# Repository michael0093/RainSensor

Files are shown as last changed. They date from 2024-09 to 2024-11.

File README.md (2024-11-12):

# RainSensor
Anti-Corrosion Rain Sensor

## Overview
Unlike the cheap rain sensors that corrode quickly this design uses a small AC signal to detect rain either resistively or capacitively. The AC signal is small enough to be below the voltage required for electrochemical corrosion thereby extending the sensor life considerably. 

In addition, this design features both analog and digital outputs and can operate from 3.3V or 5V. The on-board heater can also operate automatically when moisture is detected, or manually via a control pin.

## Pin Description
| Nbr | Name | Description 			| Specifications														|
| --- | ---	| --- | --- |
|  1  | HTR+ 	| Heater supply voltage | 5V input = 2W heater, 3.3V = 0.9W. 5V max								|
|  2  | GND  	| Ground 0V  			| Common 0V but intended mainly for heater current						|
|  3  | Heat  	| Heater control input	| 0V/open=off 3.3V-5V=on. In auto-heat mode can be used to read DigOut	|
|  4  | VDD  	| Logic supply voltage	| 3.3V-5V input. Typical current consumption 5-8mA					|
|  5  | GND  	| Ground 0V  			| Common 0V but intended mainly for logic voltage						|
|  6  | DigOut  | Digital output  		| 0V=no rain, VDD=rain. Recommend <5mA draw. Adjustable threshold.		|
|  7  | AnaOut	| Analog output			| 0V=no rain, VDD=rain. Recommend <5mA draw. Adjustable gain.			|

## Setup and Configuration Options
1. First decide if the Auto-Heat option is desired - refer to the last section of "Circuit Description" below. To enable auto heat, bridge jumper JP1, otherwise leave it open (default) to disable auto heat. 
2. Next, power up the board with the desired VDD (3.3V to 5V).

For resistive sensing mode follow the numbered steps below. Capacitive sensing mode is more durable but less sensitive - if this is desired then first cover the entire sensing area in a thin plastic tape (such as clear packaging tape) then follow the same steps below. The thinner the tape the better the sensitivity.

3. For analog output, cover the sensor element with some al-foil or other conductive material. In capacitive mode, make sure it is pressed against the sensor but do not touch it with your hands whilst adjusting the trimpots as that will affect the measurement.
4. Adjust the gain trimpot all the way counter clockwise (min gain) then slowly clockwise until the AnaOut voltage reaches the maximum ADC input voltage for your system. For example most ESP32 boards have a 1V ADC input maximum. The sensor is now ready for use.
5. For digital output use, remove the conductive material and instead apply a few drops of water. Adjust the DigOut Thresh trimpot until the orange LED lights to indicate moisture is detected. Then reduce the threshold very slightly (counter-clockwise) to give a little margin on the threshold point.
6. Install your sensor in a waterproof case and position it in an open area, angled to allow rain to slide off it preferably with the points of the sensor element pointing downwards.

## Circuit Description
Opamp U1A is configured as a relaxation oscillator with a frequency of about 6-8kHz. R5 and D1 on the output clamp the voltage to about 0.5Vpp independent of the supply voltage. This passes through C3 to make it AC-coupled into the rain sensor element. R6 and R7 keep the sensor biased around 0V. Opamp U1B is a precision rectifier configuration with gain set by RV2, and its frequency response is shaped to reject 50Hz and provide peak gain at the ~8kHz oscillator frequency. The opamp charges C5 which holds the peak voltage which is then buffered by U1C for the analog output. The digital output is handled by opamp U1D in comparator configuration with hysteresis set by R11/R10 and threshold set by RV1. 

The analog and digital outputs have 100R protection resistors near the connector which limits the practical output current to 5-10mA, however changing this resistor for 0R should provide more (limited by the opamp capabilities). 
The opamp selection is not that critical: anything capable of 3.3-5V operation, with rail-to-rail output, input bias current measured in nA, and GBWP > 500k should do. None of the other parts have any special requirements except perhaps to say that any replacement for Q1 should have similarly low gate votlage and RDson, rated at at least 1A continuous.

The LEDs are a considerable current consumer in the design and could be removed to get the current consumption down to about 4mA. If using high efficiency LEDs and a dim brightness is desired, R9=100k and R12=10k works well.

You may notice that the analog output varies by around 0.1V when the digital output changes between on and off. The reason is that oscillator U1A is slightly infleucned by U1D operating as a comparator both due to U1D's current output and the fact that it is an opamp and not ideally suited for this role. To eliminate the effect, set the DigOut thresh all the way to maximum so the LED is off and always stays off. To minimise the effect whilst still keeping the digital output, reduce R12 to a larger value such as 10k, or remove it completely if you don't need the LED.

The heater is a string of 100R 1206 resistors controlled by an N MOSFET. With the "Auto Heat" jumper open (disabled) the Heat pin controls the heater state directly. When the "Auto Heat" jumper is bridged (enabled) this connects the MOSFET to the digital output signal so that when moisture is detected the heater turns on automatically. In this configuration the Heat pin actually has several functions:
 - For pure auto-heat operation, leave the Heat pin open or connected to an input pin.
 - The Heat pin will copy the state of the DigOut pin, meaning the Heat pin can be read instead of having to run another wire for DigOut and Heat pins.
 - Driving the Heat pin high or low at any time will enable or disable the heater function, thereby over-riding the automatic behaviour.

## Modifications required for Rev A
The latest schematic includes component value changes from testing, as well as a modification that require some PCB track cutting, these changes are highlighted red on the schematic and included below as changes for the next revision.
- 

## Future changes for Rev B
The modifications required for Rev A above, plus these less-important changes to improve circuit performance/robustness:
- Polarity protection at input
- Optional position for resistor divider at digital output (to allow 3.3V logic with 5V power source): better than adjusting gain trimpot
- Low-pass filter at U1B input: 
- Look to commonise the two trimpot values to 500k
- Consider a better solution for the gain trimpot since it is either 100k-150k for resistive sense mode or 500k for capacitive sense mode
- Consider if sensor element can have more capacitive coupling (closer spacing?)

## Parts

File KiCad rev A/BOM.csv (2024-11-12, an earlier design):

Reference | Value | Footprint | Qty | DNP
C1 C2 C3 C4 C5 C6 C7 | 100nF | Capacitor_SMD:C_0603_1608Metric | 7
Cmod1 | 1nF | Capacitor_SMD:C_0603_1608Metric | 1
D1 | BAV99 | Package_TO_SOT_SMD:SOT-23 | 1
D2 | BAT54S | Package_TO_SOT_SMD:SOT-23 | 1
D3 | GREEN | LED_SMD:LED_0603_1608Metric | 1
D4 | ORANGE | LED_SMD:LED_0603_1608Metric | 1
J1 | Conn_01x07_Pin | Connector_Harwin:Harwin_M20-89007xx_1x07_P2.54mm_Horizontal | 1
Q1 | AO3400A | Package_TO_SOT_SMD:SOT-23 | 1
R1 R5 R12 R15 | 1k | Resistor_SMD:R_0603_1608Metric | 4
R2 R3 R4 R8 R9 R11 R25 | 10k | Resistor_SMD:R_0603_1608Metric | 7
R6 | 1M | Resistor_SMD:R_0603_1608Metric | 1
R7 R10 R16 | 100k | Resistor_SMD:R_0603_1608Metric | 3
R13 R14 | 100R | Resistor_SMD:R_0603_1608Metric | 2
R17 R18 R19 R20 R21 R22 R23 R24 | 100R | Resistor_SMD:R_1206_3216Metric | 8
RV1 | 10k | Potentiometer_SMD:Potentiometer_Bourns_TC33X_Vertical | 1
RV2 | 500k | Potentiometer_SMD:Potentiometer_Bourns_TC33X_Vertical | 1
U1 | LMV324 | Package_SO:SOIC-14_3.9x8.7mm_P1.27mm | 1

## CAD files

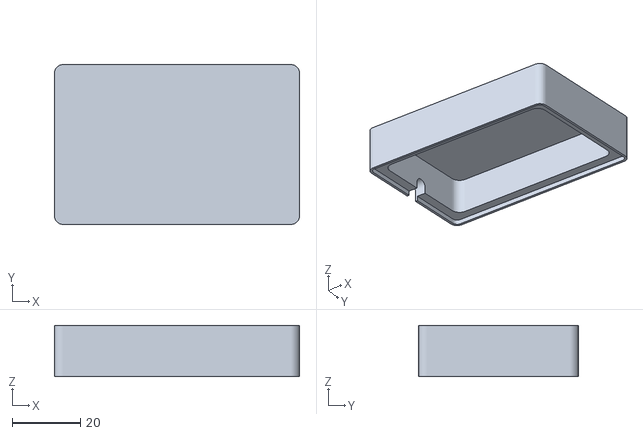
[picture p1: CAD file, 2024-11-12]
RainSensorCase.stl
71.9 x 46.9 x 15.1

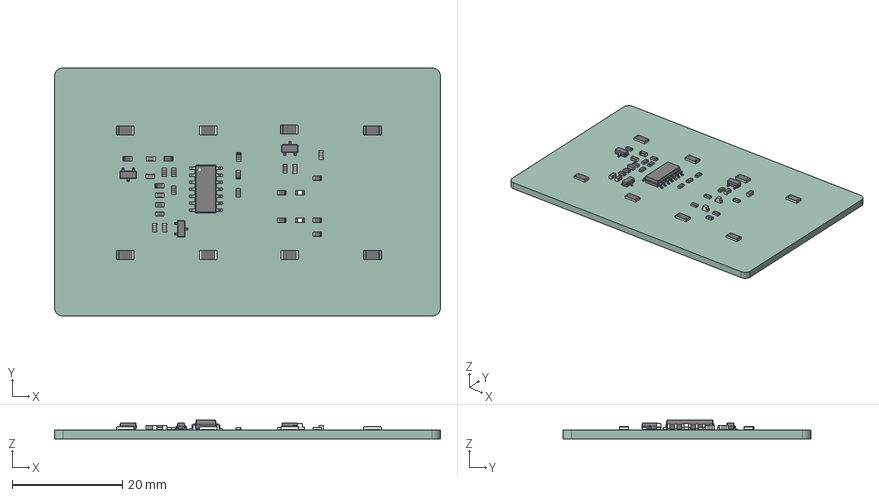
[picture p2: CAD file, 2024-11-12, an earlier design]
KiCad rev A/RainSensorPCB.step
69.9 x 44.9 x 3.40 mm
SOT_23 x 3
C_0603_1608Metric x 7
R_0603_1608Metric x 17
R_1206_3216Metric x 8
LED_0603_1608Metric x 2
SOIC_14_39x87mm_P127mm
RainSensor_PCB

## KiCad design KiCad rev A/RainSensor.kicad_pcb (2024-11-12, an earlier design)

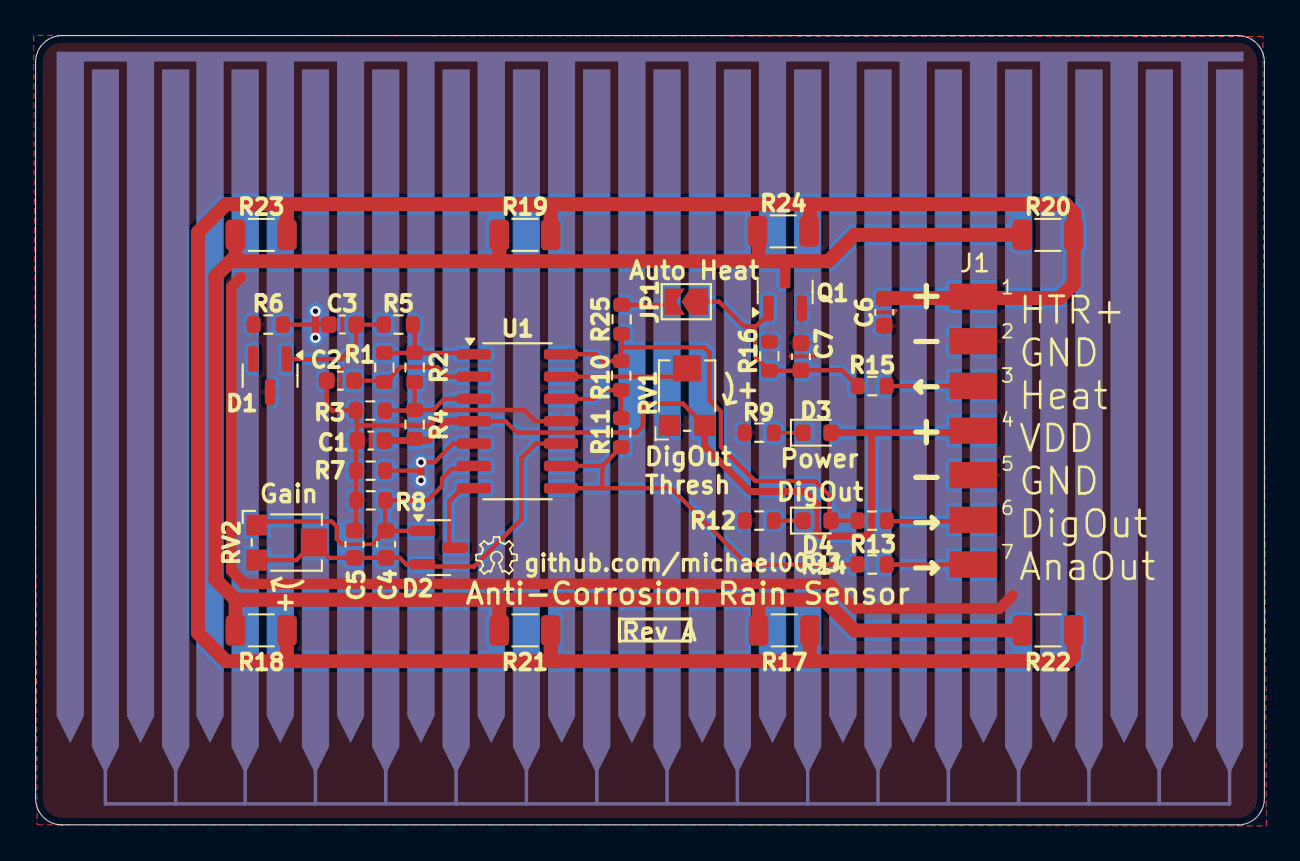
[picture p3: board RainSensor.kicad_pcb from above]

Board: 2 copper layers, 69.9 x 44.9 mm, 42 parts (0 on the bottom side), 24 nets.

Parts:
C1, C2, C3, C4, C5, C6, C7: 100nF; C_0603_1608Metric
D1: BAV99; SOT-23
D2: BAT54S; SOT-23
D3: GREEN; LED_0603_1608Metric
D4: ORANGE; LED_0603_1608Metric
J1: Conn_01x07_Pin; Harwin_M20-89007xx_1x07_P2.54mm_Horizontal_NoSilkscreen
JP1: Auto Heat; SolderJumper-2_P1.3mm_Open_TrianglePad1.0x1.5mm
Q1: AO3400A; SOT-23
R1, R5, R12, R15: 1k; R_0603_1608Metric
R2, R3, R4, R8, R9, R11, R25: 10k; R_0603_1608Metric
R6: 1M; R_0603_1608Metric
R7, R10, R16: 100k; R_0603_1608Metric
R13, R14: 100R; R_0603_1608Metric
R17, R18, R19, R20, R21, R22, R23, R24: 100R; R_1206_3216Metric
RV1: 10k; Potentiometer_Bourns_TC33X_Vertical
RV2: 500k; Potentiometer_Bourns_TC33X_Vertical
U1: LMV324; SOIC-14_3.9x8.7mm_P1.27mm

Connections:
/AnalogOut: R11.1, R14.2, U1.8, U1.9 (-)
/DigitalOut: D4.2 (A), R10.2, R13.2, R25.2, U1.14
/HeaterOn: J1.3, R15.2
GND: C1.2, C2.2, C5.2, C6.2, C7.1, D1.3 (K), J1.2, J1.5, Q1.2 (S), R3.2, R6.1, R7.1, R8.1, R9.2, R12.2, R16.1, RV1.1, U1.11 (V-)
HTR+: C6.1, J1.1, R17.2, R18.2, R19.2, R20.2, R21.2, R22.2, R23.2, R24.2
unnamed: C3.1, D1.1 (K), R5.2
unnamed: C3.2, R6.2
unnamed: C4.1, D2.1 (A), R8.2, RV2.1, U1.6 (-)
unnamed: D2.3 (COM), U1.7
unnamed: C4.2, C5.1, D2.2 (K), RV2.2, RV2.3, U1.10 (+)
unnamed: D3.1 (K), R9.1
unnamed: D4.1 (K), R12.1
unnamed: J1.6, R13.1
unnamed: J1.7, R14.1
unnamed: C7.2, JP1.1 (A), Q1.1 (G), R15.1, R16.2
unnamed: JP1.2 (B), R25.1
unnamed: Q1.3 (D), R17.1, R18.1, R19.1, R20.1, R21.1, R22.1, R23.1, R24.1
unnamed: R1.1, R2.1, R5.1, U1.1
unnamed: R2.2, R3.1, R4.1, U1.3 (+)
unnamed: C2.1, R1.2, U1.2 (-)
unnamed: R7.2, U1.5 (+)
unnamed: R10.1, R11.2, U1.12 (+)
unnamed: RV1.2, U1.13 (-)
VDD: C1.1, D3.2 (A), J1.4, R4.2, RV1.3, U1.4 (V+)

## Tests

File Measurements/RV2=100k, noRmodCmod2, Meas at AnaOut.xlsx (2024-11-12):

Time | Milliseconds | Index | Freq | Vin | Vout | dB | Column1 | Point of: | -3 | dB | AC 340mV applied at sensor side of Cmod1, Measued at AnaOut in DC mode. RV2=100k.
2024-10-06 13:23 | 5503 | 0 | 10 | 0.1207353 | 0.03446699 | -10.88861815 |  | Is at: | 377592.67 | Hz
2024-10-06 13:23 | 10777 | 1 | 10.5 | 0.1193171 | 0.03306789 | -11.1459241
2024-10-06 13:23 | 15830 | 2 | 11.03 | 0.121694 | 0.03492486 | -10.84268985
2024-10-06 13:23 | 20679 | 3 | 11.58 | 0.1215378 | 0.03483684 | -10.85345234
2024-10-06 13:23 | 25328 | 4 | 12.16 | 0.1197444 | 0.03296517 | -11.20399785
2024-10-06 13:24 | 29789 | 5 | 12.77 | 0.1219251 | 0.03512063 | -10.81061645
2024-10-06 13:24 | 34071 | 6 | 13.41 | 0.120865 | 0.03481994 | -10.80945076
2024-10-06 13:24 | 38184 | 7 | 14.08 | 0.1206078 | 0.03455034 | -10.8584614
2024-10-06 13:24 | 42142 | 8 | 14.78 | 0.1221948 | 0.0327851 | -11.42752424
2024-10-06 13:24 | 45939 | 9 | 15.52 | 0.1202407 | 0.03284157 | -11.27255171
2024-10-06 13:24 | 49586 | 10 | 16.3 | 0.1223026 | 0.03353968 | -11.2375355
2024-10-06 13:24 | 53092 | 11 | 17.12 | 0.1202784 | 0.03533784 | -10.63895284
2024-10-06 13:24 | 56464 | 12 | 17.98 | 0.1221838 | 0.03312205 | -11.33792839
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

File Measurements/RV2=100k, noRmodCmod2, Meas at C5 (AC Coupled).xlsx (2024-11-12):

Time | Milliseconds | Index | Freq | Vin | Vout | dB | Column1 | Point of: | -3 | dB | AC 340mV applied at sensor side of Cmod1, Measued at C5 in AC mode. RV2=100k.
2024-10-06 13:31 | 5507 | 0 | 10 | 0.1209953 | 0.001105958 | -40.78059732 |  | Is at: | 8399.59 | Hz
2024-10-06 13:31 | 10781 | 1 | 10.5 | 0.1196705 | 0.001414214 | -38.54943947
2024-10-06 13:31 | 15836 | 2 | 11.03 | 0.1220727 | 0.001356663 | -39.08293139
2024-10-06 13:31 | 20683 | 3 | 11.58 | 0.1218396 | 0.001333138 | -39.21826713
2024-10-06 13:31 | 25332 | 4 | 12.16 | 0.1198094 | 0.001344231 | -39.00033973
2024-10-06 13:31 | 29793 | 5 | 12.77 | 0.1222578 | 0.001385447 | -38.9137332
2024-10-06 13:32 | 34076 | 6 | 13.41 | 0.1213014 | 0.001441293 | -38.50227072
2024-10-06 13:32 | 38187 | 7 | 14.08 | 0.120941 | 0.001500502 | -38.12673953
2024-10-06 13:32 | 42138 | 8 | 14.78 | 0.1223932 | 0.001299292 | -39.4810105
2024-10-06 13:32 | 45933 | 9 | 15.52 | 0.1204099 | 0.001302121 | -39.32021705
2024-10-06 13:32 | 49583 | 10 | 16.3 | 0.1224079 | 0.001390171 | -38.89482446
2024-10-06 13:32 | 53089 | 11 | 17.12 | 0.1206534 | 0.001427114 | -38.54161796
2024-10-06 13:32 | 56462 | 12 | 17.98 | 0.1224734 | 0.001332235 | -39.26921871
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

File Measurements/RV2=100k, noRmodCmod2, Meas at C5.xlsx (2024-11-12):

Time | Milliseconds | Index | Freq | Vin | Vout | dB | Column1 | Point of: | -3 | dB | AC 340mV applied at sensor side of Cmod1, Measued at C5 in DC mode. RV2=100k.
2024-10-06 13:16 | 5503 | 0 | 10 | 0.1206232 | 0.03019208 | -12.03075624 |  | Is at: | 573.9 | Hz
2024-10-06 13:16 | 10777 | 1 | 10.5 | 0.1191344 | 0.02989424 | -12.0089933
2024-10-06 13:16 | 15831 | 2 | 11.03 | 0.1214621 | 0.03021003 | -12.08579258
2024-10-06 13:16 | 20679 | 3 | 11.58 | 0.1213122 | 0.03021546 | -12.07350537
2024-10-06 13:16 | 25329 | 4 | 12.16 | 0.1193776 | 0.02993273 | -12.0155303
2024-10-06 13:16 | 29790 | 5 | 12.77 | 0.1216803 | 0.0298685 | -12.20013718
2024-10-06 13:16 | 34072 | 6 | 13.41 | 0.1206882 | 0.02999832 | -12.09135753
2024-10-06 13:16 | 38184 | 7 | 14.08 | 0.1202617 | 0.02986978 | -12.0979063
2024-10-06 13:16 | 42134 | 8 | 14.78 | 0.1219205 | 0.02979563 | -12.23848325
2024-10-06 13:16 | 45929 | 9 | 15.52 | 0.1198481 | 0.02969256 | -12.11967021
2024-10-06 13:16 | 49578 | 10 | 16.3 | 0.1220159 | 0.02977304 | -12.25186494
2024-10-06 13:16 | 53084 | 11 | 17.12 | 0.1201503 | 0.02985347 | -12.09460082
2024-10-06 13:16 | 56456 | 12 | 17.98 | 0.1219179 | 0.03012652 | -12.14237011
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

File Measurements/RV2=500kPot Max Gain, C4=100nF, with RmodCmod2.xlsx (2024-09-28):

Time | Milliseconds | Index | Freq | Vin | Vout | dB | Phase | Point of: | -3 | dB | maxGain C4=100n
2024-09-28 16:06 | 5516 | 0 | 10 | 0.06325012 | 0.07071067 | 0.96847197 | 9.9e+37 | Is at: | #N/A | Hz
2024-09-28 16:06 | 10790 | 1 | 10.5 | 0.06237832 | 0.06054104 | -0.2596759358 | 9.9e+37
2024-09-28 16:06 | 15844 | 2 | 11.03 | 0.06360279 | 0.07071067 | 0.9201757095 | 9.9e+37
2024-09-28 16:06 | 20692 | 3 | 11.58 | 0.06352524 | 0.07071067 | 0.9307727561 | 9.9e+37
2024-09-28 16:06 | 25343 | 4 | 12.16 | 0.06258827 | 0.07134634 | 1.137575034 | 9.9e+37
2024-09-28 16:06 | 29805 | 5 | 12.77 | 0.06374215 | 0.0735893 | 1.247759277 | 9.9e+37
2024-09-28 16:06 | 34088 | 6 | 13.41 | 0.06321928 | 0.07486665 | 1.468777103 | 9.9e+37
2024-09-28 16:06 | 38201 | 7 | 14.08 | 0.06303941 | 0.06719412 | 0.5543826157 | 9.9e+37
2024-09-28 16:06 | 42152 | 8 | 14.78 | 0.06382325 | 0.07691371 | 1.620496898 | 9.9e+37
2024-09-28 16:06 | 45950 | 9 | 15.52 | 0.06278352 | 0.07870609 | 1.963253536 | 9.9e+37
2024-09-28 16:06 | 49599 | 10 | 16.3 | 0.06385795 | 0.07906435 | 1.855314648 | 9.9e+37
2024-09-28 16:06 | 53105 | 11 | 17.12 | 0.06294025 | 0.06812098 | 0.6870484712 | 9.9e+37
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

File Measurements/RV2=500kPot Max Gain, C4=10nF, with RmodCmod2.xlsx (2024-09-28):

Time | Milliseconds | Index | Freq | Vin | Vout | dB | Phase | Point of: | -3 | dB | maxGain C4=10n
2024-09-28 15:54 | 5509 | 0 | 10 | 0.06320992 | 0.07071067 | 0.9739942326 | 9.9e+37 | Is at: | #N/A | Hz
2024-09-28 15:54 | 10785 | 1 | 10.5 | 0.06228282 | 0.07071067 | 1.102333685 | 9.9e+37
2024-09-28 15:54 | 15841 | 2 | 11.03 | 0.06357542 | 0.07071067 | 0.9239142871 | 9.9e+37
2024-09-28 15:54 | 20690 | 3 | 11.58 | 0.06346412 | 0.07071067 | 0.939133797 | 9.9e+37
2024-09-28 15:54 | 25342 | 4 | 12.16 | 0.06257009 | 0.07351882 | 1.400634964 | 9.9e+37
2024-09-28 15:54 | 29803 | 5 | 12.77 | 0.06388788 | 0.07071067 | 0.8813295037 | 9.9e+37
2024-09-28 15:54 | 34085 | 6 | 13.41 | 0.06298647 | 0.0750585 | 1.52305223 | 9.9e+37
2024-09-28 15:54 | 38198 | 7 | 14.08 | 0.06297409 | 0.0707745 | 1.014298188 | 9.9e+37
2024-09-28 15:54 | 42147 | 8 | 14.78 | 0.06374811 | 0.07071067 | 0.9003527789 | 9.9e+37
2024-09-28 15:54 | 45944 | 9 | 15.52 | 0.06272613 | 0.07566207 | 1.628594499 | 9.9e+37
2024-09-28 15:55 | 49593 | 10 | 16.3 | 0.06389684 | 0.07075323 | 0.8853378024 | 9.9e+37
2024-09-28 15:55 | 53121 | 11 | 17.12 | 0.06269744 | 0.07796963 | 1.893513296 | 9.9e+37
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

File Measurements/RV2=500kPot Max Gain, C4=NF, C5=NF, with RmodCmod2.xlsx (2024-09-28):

Time | Milliseconds | Index | Freq | Vin | Vout | dB | Phase | Point of: | -3 | dB | maxGain noC4 noC5
2024-09-28 15:34 | 5506 | 0 | 10 | 0.06259557 | 0.1152923 | 5.305134093 | 9.9e+37 | Is at: | #N/A | Hz
2024-09-28 15:34 | 10782 | 1 | 10.5 | 0.06179069 | 0.1146348 | 5.367868654 | 9.9e+37
2024-09-28 15:34 | 15840 | 2 | 11.03 | 0.0629437 | 0.09998829 | 4.019937456 | 9.9e+37
2024-09-28 15:34 | 20686 | 3 | 11.58 | 0.06292506 | 0.1153111 | 5.260949535 | 9.9e+37
2024-09-28 15:34 | 25336 | 4 | 12.16 | 0.0619409 | 0.1023045 | 4.358344516 | 9.9e+37
2024-09-28 15:34 | 29800 | 5 | 12.77 | 0.06316174 | 0.1137018 | 5.106265088 | 9.9e+37
2024-09-28 15:34 | 34082 | 6 | 13.41 | 0.06259676 | 0.1139368 | 5.202243261 | 9.9e+37
2024-09-28 15:34 | 38193 | 7 | 14.08 | 0.06240263 | 0.1150716 | 5.315305161 | 9.9e+37
2024-09-28 15:34 | 42144 | 8 | 14.78 | 0.06318548 | 0.1141568 | 5.137689945 | 9.9e+37
2024-09-28 15:34 | 45941 | 9 | 15.52 | 0.06222143 | 0.1130099 | 5.183530052 | 9.9e+37
2024-09-28 15:34 | 49586 | 10 | 16.3 | 0.06325692 | 0.1017276 | 4.126615128 | 9.9e+37
2024-09-28 15:35 | 53121 | 11 | 17.12 | 0.062313 | 0.114063 | 5.251322589 | 9.9e+37
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

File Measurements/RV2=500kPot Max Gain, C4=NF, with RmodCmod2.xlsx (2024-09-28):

Time | Milliseconds | Index | Freq | Vin | Vout | dB | Phase | Point of: | -3 | dB | maxGain noC4.csv
2024-09-28 15:43 | 5521 | 0 | 10 | 0.0629506 | 0.0744433 | 1.456514858 | 9.9e+37 | Is at: | #N/A | Hz
2024-09-28 15:43 | 10795 | 1 | 10.5 | 0.06208827 | 0.09630463 | 3.81275216 | 9.9e+37
2024-09-28 15:43 | 15851 | 2 | 11.03 | 0.06333398 | 0.07482644 | 1.448366056 | 9.9e+37
2024-09-28 15:43 | 20701 | 3 | 11.58 | 0.06322526 | 0.096289 | 3.653721049 | 9.9e+37
2024-09-28 15:43 | 25351 | 4 | 12.16 | 0.06227271 | 0.09627336 | 3.784167267 | 9.9e+37
2024-09-28 15:43 | 29822 | 5 | 12.77 | 0.06345788 | 0.07530984 | 1.487323316 | 9.9e+37
2024-09-28 15:43 | 34108 | 6 | 13.41 | 0.06288776 | 0.07646015 | 1.697380396 | 9.9e+37
2024-09-28 15:43 | 38218 | 7 | 14.08 | 0.06272957 | 0.07682887 | 1.761042702 | 9.9e+37
2024-09-28 15:43 | 42172 | 8 | 14.78 | 0.06349314 | 0.07673522 | 1.645358746 | 9.9e+37
2024-09-28 15:43 | 45966 | 9 | 15.52 | 0.06253497 | 0.0772543 | 1.835994318 | 9.9e+37
2024-09-28 15:43 | 49613 | 10 | 16.3 | 0.0635898 | 0.07774411 | 1.745600743 | 9.9e+37
2024-09-28 15:43 | 53122 | 11 | 17.12 | 0.06265284 | 0.07904742 | 2.018938755 | 9.9e+37
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

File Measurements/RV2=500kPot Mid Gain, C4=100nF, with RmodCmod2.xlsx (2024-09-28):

Time | Milliseconds | Index | Freq | Vin | Vout | dB | Phase | Point of: | -3 | dB | midGain C4=100n
2024-09-28 16:14 | 5503 | 0 | 10 | 0.06317066 | 0.07071067 | 0.9793907585 | 9.9e+37 | Is at: | #N/A | Hz
2024-09-28 16:14 | 10777 | 1 | 10.5 | 0.06237325 | 0.0611949 | -0.1656628883 | 9.9e+37
2024-09-28 16:14 | 15833 | 2 | 11.03 | 0.06353669 | 0.06073408 | -0.3918425789 | 9.9e+37
2024-09-28 16:14 | 20681 | 3 | 11.58 | 0.06345331 | 0.06079187 | -0.3721755784 | 9.9e+37
2024-09-28 16:14 | 25331 | 4 | 12.16 | 0.06259324 | 0.07071067 | 1.059150398 | 9.9e+37
2024-09-28 16:14 | 29793 | 5 | 12.77 | 0.06378393 | 0.07071067 | 0.8954735568 | 9.9e+37
2024-09-28 16:14 | 34076 | 6 | 13.41 | 0.06304221 | 0.06169024 | -0.1882993899 | 9.9e+37
2024-09-28 16:14 | 38188 | 7 | 14.08 | 0.06304177 | 0.07071067 | 0.9971310826 | 9.9e+37
2024-09-28 16:14 | 42140 | 8 | 14.78 | 0.06373246 | 0.07071067 | 0.9024854046 | 9.9e+37
2024-09-28 16:14 | 45936 | 9 | 15.52 | 0.06279086 | 0.07071067 | 1.03177042 | 9.9e+37
2024-09-28 16:14 | 49585 | 10 | 16.3 | 0.06382109 | 0.07071067 | 0.8904147014 | 9.9e+37
2024-09-28 16:14 | 53091 | 11 | 17.12 | 0.06284574 | 0.06386126 | 0.1392327736 | 9.9e+37
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

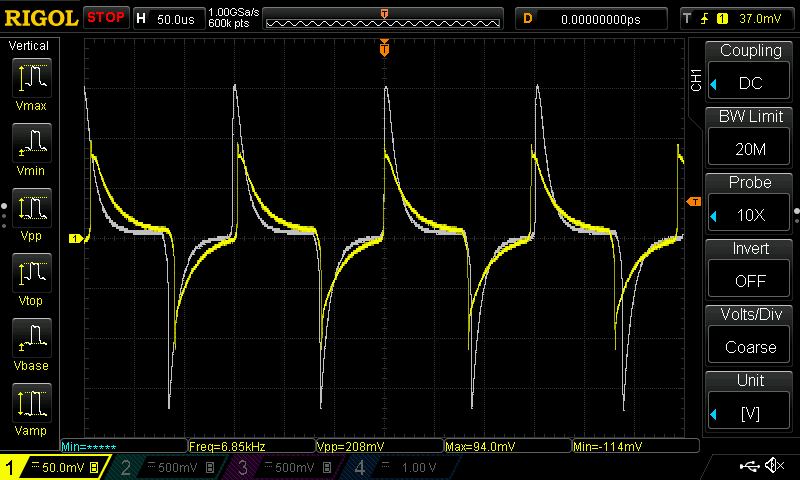
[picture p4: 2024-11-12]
Measurements/Ref=Without Cmod2Rmod1, Ch1=With.png

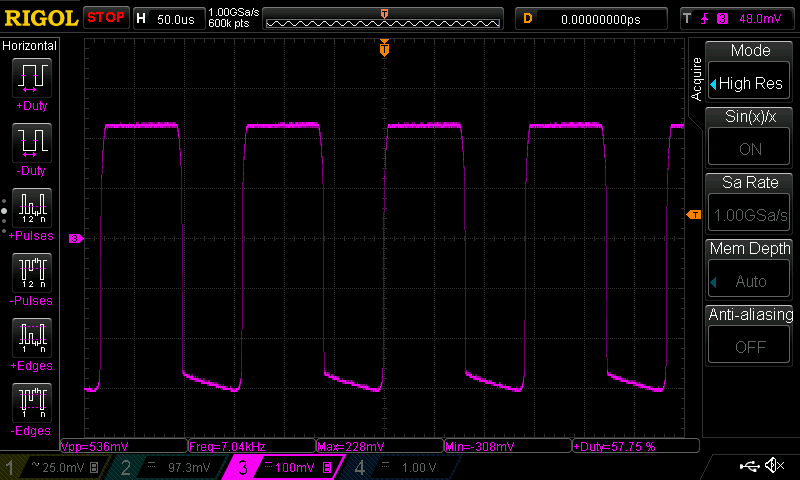
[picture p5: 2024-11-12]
Measurements/Received waveform, open cct, at Cmod1aSource waveform (at C3).png

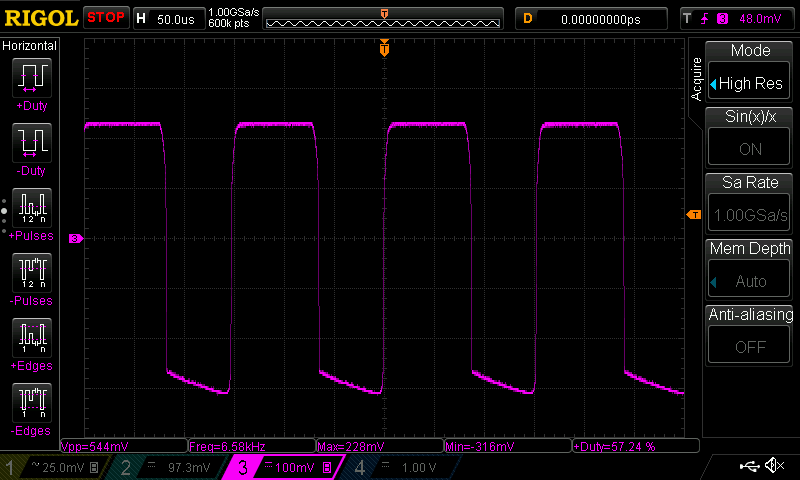
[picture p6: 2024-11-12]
Measurements/Source waveform (at C3).png

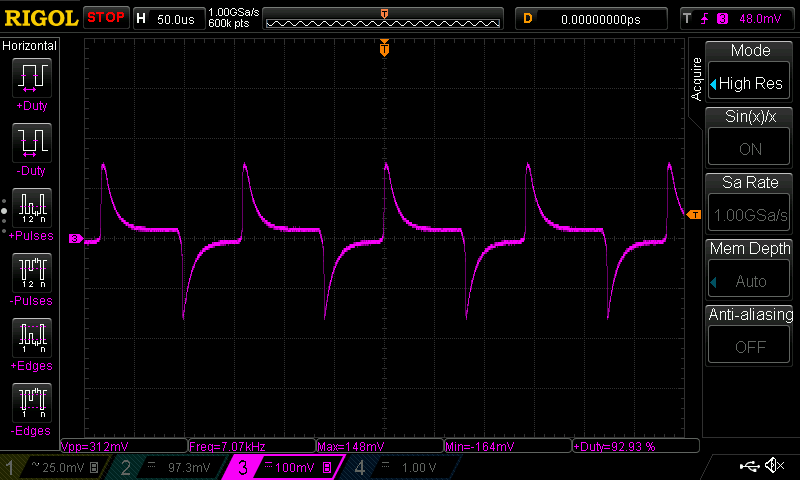
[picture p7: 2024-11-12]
Measurements/Received waveform, open cct, at Cmod1.png

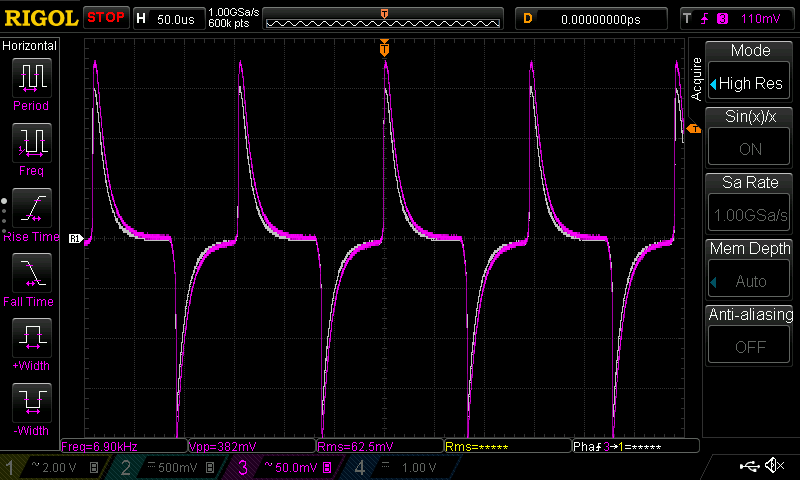
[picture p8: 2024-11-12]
Measurements/U1B+ open cct (REF) vs with capacitive coupling (Ch3).png

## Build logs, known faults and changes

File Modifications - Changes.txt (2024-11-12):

Changes for Next Revision
 Polarity protection at input
 Optional position for resistor divider at digital output (to allow 3.3V logic with 5V power source) - better than adjusting gain
 Can commonise the two trimpot values?
 Gain trimpot is either 100k-150k for conductive mode or 500k+ for capacitive mode - better solution? 
 More capacitive coupling (closer spacing?)
 Modifications as noted below

Changes from the original Rev A sch (29/06/2024) to the revised Rev A (29/09/2024):
 R10 change to XXk to increase hysteresis 
 R9 change to 10k to reduce power LED brightness. This better matches the orange LED too
 Cut track near R7 to isolate panel sense net and insert 1nF between panel sense and R7, add 100pF parallel to R7 -- filtering for 50Hz and reducing impact of capacitive coupling to improve dynamic range
 C4 = 100nF
 RV2 change to Rgain=100k since this is decent for both resistive and capacitive modes
 Add location of the anaOut scaling mod (optional)
 Change RV1 to 100k since value is not important and 100k is better for the anaout scaling mod if desired
 
**** DEVELOPMENT NOTES ****

Remark: open circuit panel is about 60pF//20Meg+
Tape + foil on about 1/3 coverage increases capacitance to 94pF, so not a very big change

Still can't get a really good capacitve sensing result. Suggest increasing drive frequency to make it easier to couple and filter 

origi osc freq, cap sense, half covered
 790mV -> 910mV
 
Increase freq by reducing C2 to 10nF
 250mV -> 330mV
 
No good, so C2 back to 100nF. Change R8 to 10k (was mod=33k) to increase gain
 1.9V-> 2.75V
 2.7-3.9 = 1.2
 2.8-4.0 = 1.2
 3.15-4.3 = 1.15
 
Increasing C4 improves distinction between on/off states
C4=100nF/200nF sense now 1.5V delta or even higher, so not too bad

Still need gain to adjust for capsense and ressense modes, probably too much variaiton for a solder jumper

HPF 10k/100pF doesnt have any real need but it should give a more robust design in the next rev

with Rmod1 Cmod2 filter = 2.93V
without filter = 2.80V
Different boards so probably not really much difference

For resistive, quarter turn of 500k is plenty = 125k, probably 100k is fine
For capacitive, also 100k

resistive no drops = 2.1V, one drop = max 4.4V
capacitive one drop = 2.3, two drops = 2.5, 3 drops = 2.8, 8 drops = 4.0. Smear large drop = 4.4V max

Anaout ripple (open sensor) = 41mVpp with 100k in place of trimmer. Add extra 100k to GND = 84mV
Add 100nF to gnd after a 100k trimmer = 0V ripple so long as the pots not in the full max position

Replace D1 with 1k and change R5 to 10k, achieves a similar voltage (0.45V) at Vin=5V, but now scales down with supply voltage.
At 3.3Vin (all values are before anaout scaling)
  open cct = 0.37. Short cct = 2.69V
  1 drop on sensor = 1.9V, 3 drops = 2.45V
capacitive mode
  1 drop = 0.45V, 3 drops = 0.63, many drops = 0.75
  
5V
open 0.75V
short 4.4V
1 drop capacitive 0.9V
3 drops capacitive 1.07V

Increase teh gain, capacitive mode.
open cct = 1.42V, many drops = 2.00

Almost max gain 
open 2.03V, many drops = 3.0V
in resistive mode 1 drop = full 4.4V output

Ok so dont change the diode, change the gain. Dont want to waste our 600mV max on the sensor.
Retain RV2=100k, but add option for parallel 100k to make gain 50k for 3.3V operation, this gives us the margin we need again without compromising on sensor votlage. Retest:

3.3Vin with RV2=50k
open = 1.20V
change RV2=100k, 3.3Vin open/short = 1.81V/3.29, 5Vin = 1.85V/4.41V

Unity buffer is saturating when the comparator turns on. somethings not right there
> Disconnected R11, its still bad, depends on Vin. Something else going on...
Reason is the LMV324 common mode input range only extends down to 0V, not up to VCC. In fact the maximum for 5V is 4.2V typ which is about what we see fortunately. It gets more noticable at 3.3V where the limit appears to be more like 2.8V. This might be the reason for the odd behaviour of the comparator mode too. 
Solution is to make sure to divide the anaout signal before the unity buffer, and make sure the desired anaout range is lower than the supplied VCC.
To avoid this issue for the test results below, the anaout was scaled down 

VCC 3.3V, gain=50k, 
short = 2.00V
open = 0.95V =48%
capacitive 1 drop = 1.07=54%, 2 drops = 1.22=61%, 3 drops = 1.3=65%, big smear = 1.8
5V smear = 2.00, open = 0.98

VCC 3.3V, gain=100k,
short = 2.06V
open = 1.44V=72%
capacitive 1 drop = 1.62=81%, 2 drops = 1.75=88%, 3 drops = 1.81, big smear = 1.96
5V smear = 2.84, open = 1.54

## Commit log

2024-09-28 First commit, with 29/06/2024 schematic as originally designed before any modifications.
    [20240928_153407_Bode maxGain noC4 noC5.csv, 20240928_154305_Bode maxGain noC4.csv, 20240928_155411_Bode maxGain C4=10n.csv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]
2024-11-12 Add rev B Kicad project, schematic updated.
    [20240928_153407_Bode maxGain noC4 noC5.csv, 20240928_154305_Bode maxGain noC4.csv, 20240928_155411_Bode maxGain C4=10n.csv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]
